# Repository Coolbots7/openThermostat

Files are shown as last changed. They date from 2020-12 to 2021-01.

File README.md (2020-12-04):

# openThermostat
openThermostat is an open source smart thermostat. It utilizes an ESP8266 to provide a web based API for easy integration.

# Documentation
All documentation is available in the Wiki which can be found [here](https://github.com/Coolbots7/openThermostat/wiki)

# Contributors
* [Brian Bugert](https://github.com/Coolbots7)
* [Fletcher Porter](https://github.com/fpdotmonkey)

# Bug Reporting
If you found a bug please open a [GitHub issue](https://github.com/Coolbots7/openThermostat/issues/new) and describe the problem with as much detail as possible. Bug descriptions should include:
* A brief and easy to understand title
* Step-by-step instructions on how to reproduce the bug

# Contributing
Contributions are welcome! Please reference the [contribution guidelines](CONTRIBUTING.md) before you start.

## TLDR
1. Fork it
2. Create your feature branch (`git checkout -b feature/fooBar`)
3. Commit your changes (`git commit -am 'Add some fooBar'`)
4. Push to the branch (`git push origin feature/fooBar`)
5. Create a new Pull Request

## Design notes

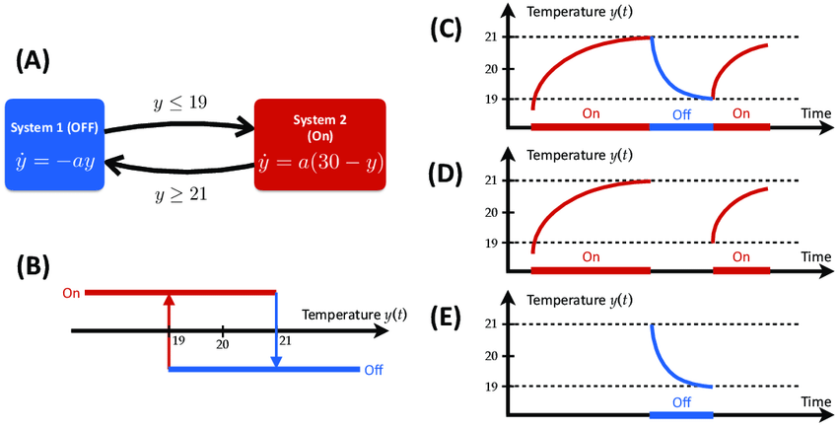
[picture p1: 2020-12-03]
docs/Thermostat-example-A-The-physical-dynamic-equations-plus-the-transition-rules-of-the.png

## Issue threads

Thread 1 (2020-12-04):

Enclosure & Mount

Coolbots7, 2020-12-04:
Design an enclosure for the electronics and a wall mount with screw terminals for wiring connections.

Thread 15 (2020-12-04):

Add pull down resistor to transistor base

Coolbots7, 2020-12-04:
Relay being turned on then off when microcontroller reboots. Try adding a pull down to the transistor base to prevent floating.

Coolbots7, 2020-12-10:
Adding 10k resistor between base and ground didnt have an effect during reboot

Closed 2020-12-10.

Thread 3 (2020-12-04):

Battery & USB Charging

Coolbots7, 2020-12-04:
Add a rechargeable battery to provide power when a 24v power supply is not available. Add a USB C charging port to recharge the battery.

Coolbots7, 2020-12-04:
Need to determine what capacity battery is needed.

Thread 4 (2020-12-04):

Control voltage inline charging

Coolbots7, 2020-12-04:
Place a battery charger in series with the control voltage supply and the returns. This will allow the battery to charge off of the current flow of the returned control voltage.

Coolbots7, 2020-12-04:
Will need to limit the current used to charge the battery.

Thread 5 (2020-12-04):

Add physical buttons

Coolbots7, 2020-12-04:
Add buttons to the device to change the mode and setpoint.

Coolbots7, 2020-12-04:
*cough* Capacitive touch sensors *chough*

Closed 2021-01-03.

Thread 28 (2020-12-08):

Add battery monitoring

Coolbots7, 2020-12-08:
- [ ] Add battery level monitoring
- [ ] show low battery on screen
- [ ] add battery level. voltage, and current to API

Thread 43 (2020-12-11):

Create 0.2.0 schematic

Coolbots7, 2020-12-11:
* Microcontroller
* Sensor
* Screen
* Heater Relay
* AC Relay
* Fan Relay
* Temp buttons
* Control button
* Expose unused microcontroller pins
* Expose microcontroller communication pins

Closed 2021-01-03.

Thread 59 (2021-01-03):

Fix screen wiring on PCB

Coolbots7, 2021-01-03:

Closed 2021-01-03.

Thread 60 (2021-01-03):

Fix front button wiring on PCB

Coolbots7, 2021-01-03:
Front buttons wired to wrong pads on button footprint

Closed 2021-01-03.

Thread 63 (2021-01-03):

Fix power switch footprint wiring

Coolbots7, 2021-01-03:
Make sure nets on power switch footprint connect to both pads

Closed 2021-01-03.

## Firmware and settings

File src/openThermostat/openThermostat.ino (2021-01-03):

#include <WiFi.h>
#include <WiFiClient.h>
#include <WebServer.h>
#include <ESPmDNS.h>

#include <SPI.h>
#include <Adafruit_Sensor.h>
#include <Adafruit_BME280.h>

#include "Display.h"
#include "PersistentStorage.h"
#include "Thermostat.h"
#include "WebService.h"
#include "Button.h"

// End user specific config file for WiFi network settings
#include "wifi.h"

// ====== Factory Reset Settings ======
#define FACTORY_RESET_TIME 5000
#define FACTORY_RESET_PIN 2

// ====== WiFi Settings ======
// Override SSID and password definitions in wifi.h which is excluded from source control
#ifndef STASSID
#define STASSID "your-ssid"
#define STAPSK "your-password"
#endif

#ifndef PORT
#define PORT 80
#endif

// ====== Relay Settings ======
#define HEAT_RELAY_PIN 26
#define COOL_RELAY_PIN 27
#define FAN_RELAY_PIN 14

// ====== Environmental Sensor Settings ======
#define BME_CS_PIN 33
Adafruit_BME280 bme(BME_CS_PIN); // hardware SPI

#define ENVIRONMENTAL_SENSOR_UPDATE_PERIOD 2000

// ====== Thermostat ======
#ifndef DEFAULT_HEAT_SETPOINT
#define DEFAULT_SETPOINT_LOW 22
#define DEFAULT_SETPOINT_HIGH 25
#endif

// ====== Display Settings ======
#define SCREEN_BRIGHTNESS 1
#define SCREEN_UPDATE_PERIOD 1000

// ====== Button Settings ======
#define UP_BUTTON_PIN 5
#define DOWN_BUTTON_PIN 4
#define MULTI_BUTTON_PIN 15

// ====== Globals ======

float currentTemperature = NAN;
float currentHumidity = NAN;

Display *display;

PersistentStorage *storage;

Thermostat *thermostat;

WebService *webService;

Button *upButton;
Button *downButton;
Button *multiButton;

void (*resetFunc)(void) = 0; //declare reset function @ address 0

void setup()
{
  Serial.begin(115200);

  // ====== Initialize relays ======
  pinMode(HEAT_RELAY_PIN, OUTPUT);
  digitalWrite(HEAT_RELAY_PIN, LOW);

  pinMode(COOL_RELAY_PIN, OUTPUT);
  digitalWrite(COOL_RELAY_PIN, LOW);

  pinMode(FAN_RELAY_PIN, OUTPUT);
  digitalWrite(FAN_RELAY_PIN, LOW);

  // ====== Create Display ======
  display = new Display();
  display->setBrightness(SCREEN_BRIGHTNESS);

  // Factory reset
  pinMode(FACTORY_RESET_PIN, INPUT);
  if (digitalRead(FACTORY_RESET_PIN) == HIGH)
  {
    unsigned long factoryResetStartTime = millis();
    while (millis() < factoryResetStartTime + FACTORY_RESET_TIME && digitalRead(FACTORY_RESET_PIN) == HIGH)
    {
      // Show factory reset pending on screen
      display->factoryResetPending(String(ceil(((factoryResetStartTime + FACTORY_RESET_TIME) - millis()) / 1000)));

      Serial.print("Factory resetting in ");
      Serial.print(ceil(((factoryResetStartTime + FACTORY_RESET_TIME) - millis()) / 1000));
      Serial.println(" sec");
      delay(500);
    }
    if (digitalRead(FACTORY_RESET_PIN) == HIGH)
    {
      //Factory resetting on screen
      display->factoryResetting();
      Serial.print("Resetting...");

      storage->setCurrentThermostatMode(Thermostat::ThermostatMode::OFF);
      storage->setCurrentThermostatState(Thermostat::ThermostatState::IDLE);
      storage->setSetpointLow(DEFAULT_SETPOINT_LOW);
      storage->setSetpointHigh(DEFAULT_SETPOINT_HIGH);
      Serial.print("thermostat reset...");

      storage->setSettingScreenImperial(false);
      storage->setSettingUseRemoteTemperature(false);
      Serial.print("storage reset...");
      delay(200);

      //Show factory reset on screen
      display->factoryResetComplete();
      Serial.println("Reset Complete!");

      while (digitalRead(FACTORY_RESET_PIN) == HIGH)
      {
        delay(100);
      }
      resetFunc();
    }
  }

  // Show welcome screen
  display->welcome();

  // ====== Initialize WiFi ======
  // TODO move WiFi connection to WebServer class while still showing progress on screen
  const char *ssid = STASSID;
  const char *password = STAPSK;
  WiFi.mode(WIFI_STA);
  WiFi.begin(ssid, password);
  Serial.println("");
  Serial.print("Connecting to WiFi network: ");
  Serial.print(ssid);

  bool wifiLoading = false;
  // Wait for connection
  while (WiFi.status() != WL_CONNECTED)
  {
    Serial.print(".");

    // Show wifi status on screen
    display->wifiConnecting(ssid);
    wifiLoading = !wifiLoading;

    delay(500);
  }

  if (MDNS.begin("esp32"))
  {
    Serial.println("MDNS responder started");
  }

  Serial.println("");
  Serial.print("Connected to ");
  Serial.println(ssid);
  Serial.print("IP address: ");
  Serial.println(WiFi.localIP());

  // Show wifi connected on screen
  display->wifiConnected(WiFi.localIP().toString());

  // ====== Initialize temperature sensor ======
  // TODO show temperature initialization on screen
  if (!bme.begin())
  {
    Serial.println("Failed to initialize BME sensor");
    for (;;)
    {
    }
  }

  // ====== Get Persistent Storage singleton
  storage = storage->getInstance();

  // ====== Get Thermostat singleton
  thermostat = thermostat->getInstance();

  // ====== Initialize Web Service ======
  int port = PORT;
  webService = new WebService(port);

  // ====== Initialize Buttons ======
  upButton = new Button(UP_BUTTON_PIN, &upButtonPressed);
  downButton = new Button(DOWN_BUTTON_PIN, &downButtonPressed);
  multiButton = new Button(MULTI_BUTTON_PIN, &multiButtonPressed);
}

unsigned long lastEnvironemntalSensorUpdateTime = 0;
unsigned long lastScreenUpdateTime = 0;

void loop()
{
  upButton->update();
  downButton->update();
  multiButton->update();

  // Update temperature and humidity
  if (millis() >= lastEnvironemntalSensorUpdateTime + ENVIRONMENTAL_SENSOR_UPDATE_PERIOD)
  {
    lastEnvironemntalSensorUpdateTime = millis();

    // Reading temperature or humidity takes about 250 milliseconds!
    // Sensor readings may also be up to 2 seconds 'old' (its a very slow sensor)
    float tempHumidity = bme.readHumidity();
    // Read temperature as Celsius (the default)
    float tempTemperature = bme.readTemperature();

    if (isnan(tempHumidity) || isnan(tempTemperature))
    {
      Serial.println(F("Failed to read from environmental sensor!"));
    }
    else
    {
      currentHumidity = tempHumidity;
      currentTemperature = tempTemperature;

      Serial.print("Temp: ");
      Serial.print(currentTemperature);
      Serial.print("°C    Hum: ");
      Serial.print(currentHumidity);
      Serial.println("%");
    }
  }

  // Check remote temperature
  if (storage->getSettingUseRemoteTemperature())
  {
    currentTemperature = webService->getRemoteTemperature();
  }

  // Update WiFi
  webService->update(currentTemperature, currentHumidity);

  //Update thermostat
  Thermostat::ThermostatState state = thermostat->update(currentTemperature);
  if (state == Thermostat::ThermostatState::IDLE)
  {
    digitalWrite(HEAT_RELAY_PIN, LOW);
    digitalWrite(COOL_RELAY_PIN, LOW);
    digitalWrite(FAN_RELAY_PIN, LOW);
  }
  else if (state == Thermostat::ThermostatState::HEATING)
  {
    digitalWrite(HEAT_RELAY_PIN, HIGH);
    digitalWrite(COOL_RELAY_PIN, LOW);
    digitalWrite(FAN_RELAY_PIN, LOW);
  }
  else if (state == Thermostat::ThermostatState::COOLING)
  {
    digitalWrite(HEAT_RELAY_PIN, LOW);
    digitalWrite(COOL_RELAY_PIN, HIGH);
    digitalWrite(FAN_RELAY_PIN, LOW);
  }
  else if (state == Thermostat::ThermostatState::FAN)
  {
    digitalWrite(HEAT_RELAY_PIN, LOW);
    digitalWrite(COOL_RELAY_PIN, LOW);
    digitalWrite(FAN_RELAY_PIN, HIGH);
  }

  if (millis() >= lastScreenUpdateTime + SCREEN_UPDATE_PERIOD)
  {
    lastScreenUpdateTime = millis();
    // Update display
    display->main(currentTemperature, currentHumidity);
  }

  delay(30);
}

void upButtonPressed()
{
  if (thermostat->getMode() == Thermostat::ThermostatMode::AUTOMATIC)
  {
    //Increase 1 degree of current screen unit
    double increase = 1;
    // if (storage->getSettingScreenImperial() == true)
    // {
    //   increase = 1.8;
    // }

    thermostat->setSetpointLow(thermostat->getSetpointLow() + increase);
  }
}

void downButtonPressed()
{
  if (thermostat->getMode() == Thermostat::ThermostatMode::AUTOMATIC)
  {
    //Decrease 1 degree of current screen unit
    double decrease = 1;
    // if (storage->getSettingScreenImperial() == true)
    // {
    //   decrease = 1.8;
    // }

    thermostat->setSetpointLow(thermostat->getSetpointLow() - decrease);
  }
}

void multiButtonPressed()
{
  Thermostat::ThermostatMode mode = thermostat->getMode();

  if (mode == Thermostat::ThermostatMode::OFF)
  {
    thermostat->setMode(Thermostat::ThermostatMode::AUTOMATIC);
  }
  else if (mode == Thermostat::ThermostatMode::AUTOMATIC)
  {
    thermostat->setMode(Thermostat::ThermostatMode::HEAT);
  }
  else if (mode == Thermostat::ThermostatMode::HEAT)
  {
    thermostat->setMode(Thermostat::ThermostatMode::OFF);
  }
  else
  {
    thermostat->setMode(Thermostat::ThermostatMode::OFF);
  }
}

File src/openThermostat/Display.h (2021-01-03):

#ifndef DISPLAY_H
#define DISPLAY_H

#include <SPI.h>
#include <TFT_eSPI.h> // Hardware-specific library

#include "Temperature.h"
#include "PersistentStorage.h"
#include "Thermostat.h"

// ====== Screen Hardware Settings ======
// #define SCREEN_WIDTH 320  // OLED display width, in pixels
// #define SCREEN_HEIGHT 240 // OLED display height, in pixels

#define TFT_WIDTH 320  // ST7789 240 x 240 and 240 x 320
#define TFT_HEIGHT 240 // ST7789 240 x 320

// Definitions for ST7789V display using SPI

#define TFT_MISO 19
#define TFT_MOSI 23
#define TFT_SCLK 18

//PCB v0.1.0
// #define TFT_CS   35  // Chip select control pin
// #define TFT_DC    32  // Data Command control pin
// #define TFT_RST   34  // Reset pin (could connect to RST pin)

// PCB Headers
#define TFT_CS 13  // Chip select control pin
#define TFT_DC 17  // Data Command control pin
#define TFT_RST 12 // Reset pin (could connect to RST pin)

// #define SCREEN_CS 13
// #define SCREEN_RESET 12
// #define SCREEN_DC 17
// #define SCREEN_MOSI 23
// #define SCREEN_MISO 19
// #define SCREEN_SCLK 18

#define SCREEN_ORIENTATION 1

// ====== Backlight Settings ======
#define SCREEN_BACKLIGHT_PIN 25

// use first channel of 16 channels (started from zero)
#define LEDC_CHANNEL_0 0

// use 13 bit precission for LEDC timer
#define LEDC_TIMER_13_BIT 13

// use 5000 Hz as a LEDC base frequency
#define LEDC_BASE_FREQ 5000

// ====== Animation Settings ======
#define TFT_FONT 2

#define WELCOME_PAUSE 1500
#define WIFI_CONNECTED_PAUSE 1500

class Display
{
private:
  TFT_eSPI *tft;

  PersistentStorage *storage;

  Thermostat *thermostat;

  bool wifiLoading;

  double brightness;

public:
  Display()
  {
    // ======Initialize Screen ======
    tft = new TFT_eSPI();
    tft->init();
    tft->setRotation(SCREEN_ORIENTATION);
    tft->setTextSize(1.5);
    tft->fillScreen(TFT_BLACK);
    tft->setTextColor(TFT_WHITE, TFT_BLACK); // Adding a background colour erases previous text automatically

    // ====== Initialize Backlight ======
    // Setup timer and attach timer to a led pin
    ledcSetup(LEDC_CHANNEL_0, LEDC_BASE_FREQ, LEDC_TIMER_13_BIT);
    ledcAttachPin(SCREEN_BACKLIGHT_PIN, LEDC_CHANNEL_0);

    storage = storage->getInstance();

    thermostat = thermostat->getInstance();
  }

  // Factory Reset Pending
  void factoryResetPending(String countdown)
  {
    tft->fillScreen(TFT_BLACK);
    tft->setTextColor(TFT_WHITE, TFT_BLACK);

    String text = "Factory reset in: " + countdown + "s";
    tft->drawCentreString(text, TFT_WIDTH / 2, TFT_HEIGHT / 2, TFT_FONT);
  }

  // Factory Resetting
  void factoryResetting()
  {
    tft->fillScreen(TFT_BLACK);
    tft->setTextColor(TFT_WHITE, TFT_BLACK);

    tft->drawCentreString("Resetting...", TFT_WIDTH / 2, TFT_HEIGHT / 2, TFT_FONT);
  }

  // Factory Reset
  void factoryResetComplete()
  {
    tft->fillScreen(TFT_BLACK);
    tft->setTextColor(TFT_WHITE, TFT_BLACK);

    tft->drawCentreString("Factory Reset Complate!", TFT_WIDTH / 2, TFT_HEIGHT / 2, TFT_FONT);
  }

  // Welcome
  void welcome()
  {
    tft->fillScreen(TFT_BLACK);
    tft->setTextColor(TFT_WHITE, TFT_BLACK);

    tft->drawCentreString("Welcome to openThermostat", TFT_WIDTH / 2, TFT_HEIGHT / 2, TFT_FONT);

    delay(WELCOME_PAUSE);
  }

  // Wifi connecting
  void wifiConnecting(String ssid)
  {
    tft->fillScreen(TFT_BLACK);
    tft->setTextColor(TFT_WHITE, TFT_BLACK);

    tft->drawCentreString("Connecting to WiFi Network: " + ssid, TFT_WIDTH / 2, TFT_HEIGHT / 2, TFT_FONT);
  }

  // Wifi connected
  void wifiConnected(String ip)
  {
    tft->fillScreen(TFT_BLACK);
    tft->setTextColor(TFT_WHITE, TFT_BLACK);

    String ipStr = "IP: " + ip;

    tft->drawCentreString("Connected! " + ipStr, TFT_WIDTH / 2, TFT_HEIGHT / 2, TFT_FONT);

    delay(WIFI_CONNECTED_PAUSE);
  }

  //Main thermostat display
  void main(double currentTemperature, double currentHumidity)
  {
    tft->fillScreen(TFT_BLACK);
    tft->setTextColor(TFT_WHITE, TFT_BLACK);

    //current temperature
    String tempString = "";
    if (isnan(currentTemperature))
    {
      tempString += "NAN";
    }
    else
    {
      if (storage->getSettingScreenImperial())
      {
        tempString += String((uint8_t)round(celsiusToFahrenheit(currentTemperature))) + "°F";
      }
      else
      {
        tempString += String((uint8_t)round(currentTemperature)) + "°C";
      }
    }
    //Show that temperature is remote
    if (storage->getSettingUseRemoteTemperature())
    {
      tempString += "R";
    }
    tft->setTextSize(6);
    tft->drawCentreString(tempString, 150, TFT_HEIGHT / 2 - 50, TFT_FONT);

    //humidity
    String humidityString = "";
    if (isnan(currentHumidity))
    {
      humidityString += "NAN";
    }
    else
    {
      humidityString += String((uint8_t)currentHumidity) + "%";
    }
    tft->setTextSize(2);
    tft->drawCentreString(humidityString, TFT_WIDTH / 3, TFT_HEIGHT / 2 + 50, TFT_FONT);

    //setpoint
    if ((Thermostat::ThermostatMode)thermostat->getMode() == Thermostat::ThermostatMode::AUTOMATIC)
    {
      String setpointString = "";
      if (storage->getSettingScreenImperial())
      {
        setpointString += String((uint8_t)celsiusToFahrenheit(thermostat->getSetpointLow())) + "-";
        setpointString += String((uint8_t)celsiusToFahrenheit(thermostat->getSetpointHigh())) + "°F";
      }
      else
      {
        setpointString += String((uint8_t)thermostat->getSetpointLow()) + "-";
        setpointString += String((uint8_t)thermostat->getSetpointHigh()) + "°C";
      }
      tft->setTextSize(1);
      tft->drawCentreString(setpointString, TFT_WIDTH - 60, TFT_HEIGHT / 2 + 30, TFT_FONT);
    }

    //mode
    String modeStr = thermostat->getModeString();
    modeStr.toUpperCase();
    tft->setTextSize(1);
    tft->drawCentreString(modeStr, TFT_WIDTH - 60, TFT_HEIGHT / 2 - 30, TFT_FONT);

    String stateStr = thermostat->getStateString();
    stateStr.toUpperCase();
    tft->setTextSize(1);
    tft->drawCentreString(stateStr, TFT_WIDTH - 60, TFT_HEIGHT / 2, TFT_FONT);
  }

  //Backlight brightness control
  void setBrightness(double brightness)
  {
    //cap brightness from 0.0 to 1.0
    if (brightness < 0)
    {
      brightness = 0;
    }
    if (brightness > 1)
    {
      brightness = 1;
    }

    this->brightness = brightness;

    ledcWrite(LEDC_CHANNEL_0, round(8191 * brightness));
  }

  double getBrightness()
  {
    return this->brightness;
  }
};

#endif

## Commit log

2020-12-01 Create Arduino sketch
2020-12-01 Print temp and humidity to serial
2020-12-02 Add furnace relay and show on screen
2020-12-03 Add EEPROM storage and factory reset
    [PersistentStorage.h, openThermostat.ino]
2020-12-04 standardize endpoint heating state
2020-12-04 return current setpoint in celsius
2020-12-08 Fix printing setpoint floating point precision on screen
    [openThermostat.ino]
2020-12-08 Add use remote temperature setting
2020-12-08 Add API temperature endpoint
2020-12-09 Use remote temperature in thermostat.
2020-12-09 Show remote temperature on screen
2020-12-09 Add use remote temperature setting to API. closes #2
2020-12-09 Return passed temperature on temp post
2020-12-10 Fix thermostat class singleton. closes #30
    [Thermostat.h, openThermostat.ino]
2020-12-11 create 0.1.0 schematic. closes #17
    [openThermostat_Schematic_v1.sch]
2020-12-18 Switch to KiCAD
    [openThermostat.kicad_pcb, openThermostat.sch, openThermostat_Schematic_v1.sch]
2020-12-28 create pcb v0.2.0
    [openThermostat-B_Cu.gbr, openThermostat-B_Mask.gbr, openThermostat-B_SilkS.gbr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]
2020-12-30 Fix persistent storage for ESP32
    [PersistentStorage.h, Thermostat.h, openThermostat.ino]
2020-12-30 Change web server for ESP32 closes #49
2020-12-30 Update factory reset pin number
2020-12-30 Update heat relay pin name and number. closes #48
2020-12-30 Update to BME230 environmental sensor. closes #47
2020-12-30 Fix switch statements for ESP32
    [Thermostat.h]
2020-12-30 Add fan control. closes #26
2021-01-02 fix thermostat auto state machine logic
    [Thermostat.h]
2021-01-03 Update schematic for screen fix. closes #59
    [openThermostat.kicad_pcb, openThermostat.sch]
2021-01-03 Fix B3FS-100xP button footprint. closes #60
    [openThermostat.kicad_pcb]
2021-01-03 Add front control buttons. closes #46
2021-01-03 Fix power switch connections. closes #63
    [openThermostat.kicad_pcb]
2021-01-03 Add RST and DTR to FTDI header. closes #62
    [openThermostat.kicad_pcb, openThermostat.sch]
